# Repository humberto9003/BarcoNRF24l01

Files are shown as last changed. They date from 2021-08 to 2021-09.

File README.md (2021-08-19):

# Enlace con NRF24L01
Este repositorio contiene el programa para comunicar dos modulos NRF24L01, enviando las señales analogicas de un joystick por radiocomunicacion (2.4GHZ) para controlar un servomotor SG90 y un motor Brushless.

### Requisitos
Para que el código de este repositorio funcione, es necesario contar con lo siguiente:

- Arduino Uno
- IDE de Arduino 1.8 o superior
- Biblioteca RF24
- Servomotor SG90
- Motor Brushless A2212 Kv1400 / Kv2200
- NRF24L01
- Regulador de Voltaje para el NR24L01
- Modulo Joystick de dos ejes.

### Guías

Puedes obtener la biblioteca RF24 desde el siguiente enlace.

https://github.com/nRF24/RF24

Para conocer mas acerca del modulo NRF24L01 puede consultarlo en el siguiente enlace.

http://robots-argentina.com.ar/didactica/arduino-comunicacion-inalambrica-con-nrf24l01/

### Funcionamiento

Para observar el funcionamiento de este proyecto deberás realizar lo siguiente.

1. Configuarar los pines para el motor,servomotor y joystick de tu preferencia en el codigo de RX y Tx.
2. Si no cunetas con un NodeMCU se puede sustituir con otro arduino, solo tendrias que configuarar los pines de igual manera que el codigo de TX.
3. Alimentar el modulo NRF24L01 unicamete y exclusivamente con el regulador de  3.3V
4. En caso de usar el motor alimentarlo de una bateria externa y no del arduino ya que este no proporciona la corriente suficiente.

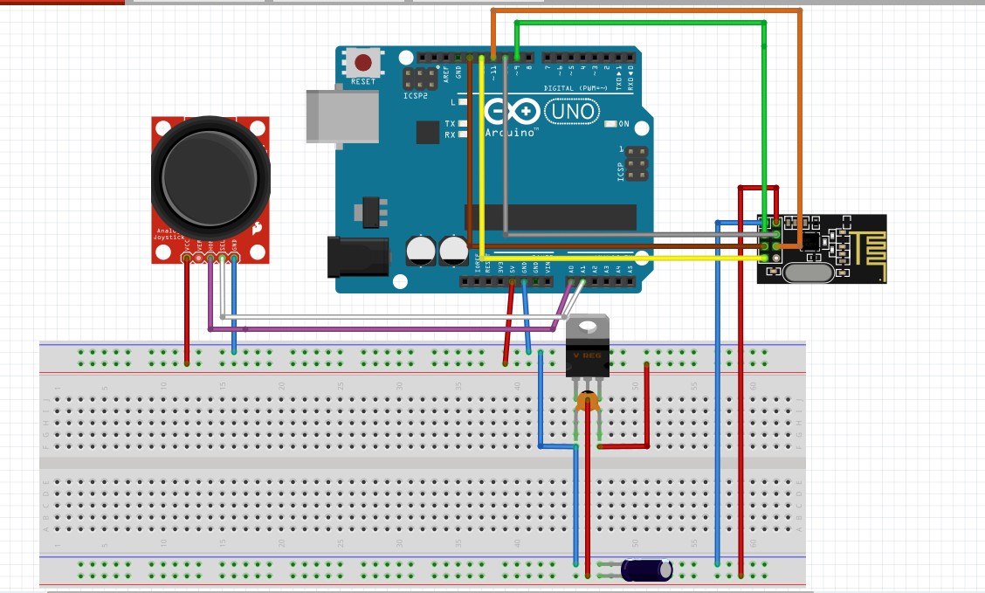
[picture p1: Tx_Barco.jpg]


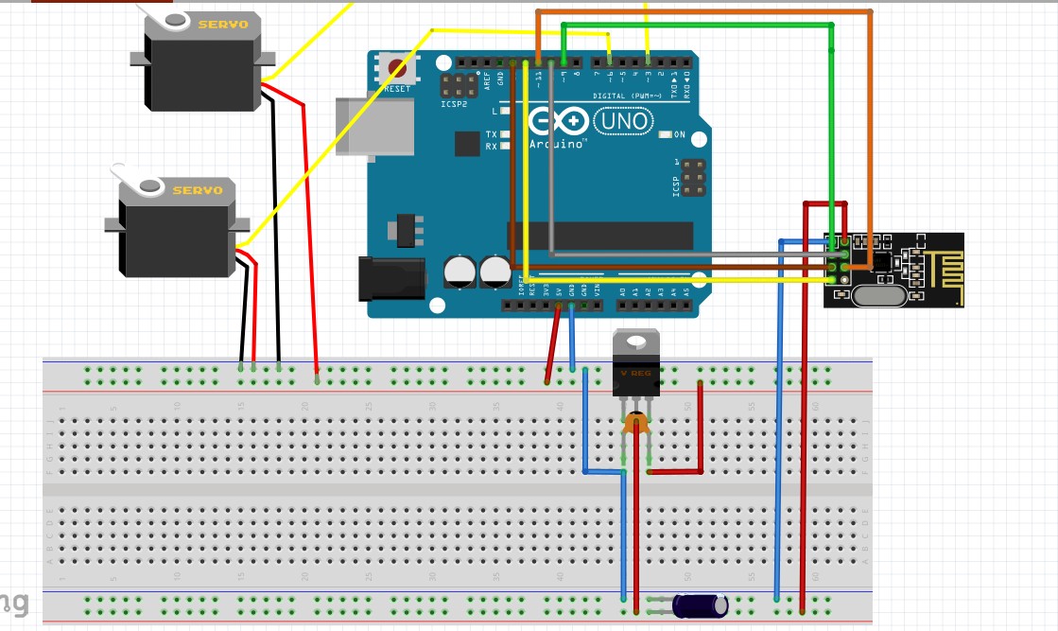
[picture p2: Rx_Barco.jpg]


Podras comunicar dos arduinos por radiocomunicación, para este caso en particular poder manipular un servomor y motor con un Joystick. 

Por: [Humberto Pastor](https://https://github.com/humberto9003)

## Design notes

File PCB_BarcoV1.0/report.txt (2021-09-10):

Información: Checking netlist symbol footprint "J1:/60B9BEF3:TerminalBlock_Phoenix:TerminalBlock_Phoenix_PT-1,5-2-5.0-H_1x02_P5.00mm_Horizontal".
Información: Checking netlist symbol footprint "Y1:/60B92542:Crystal:Crystal_HC49-4H_Vertical".
Información: Checking netlist symbol footprint "U3:/60B7981D:Package_DIP:DIP-28_W7.62mm".
Información: Checking netlist symbol footprint "U2:/60B07A03:Package_TO_SOT_SMD:SOT-223-3_TabPin2".
Información: Checking netlist symbol footprint "U1:/60B08B95:Package_TO_SOT_SMD:SOT-223-3_TabPin2".
Información: Checking netlist symbol footprint "SW1:/60C895E8:Button_Switch_THT:SW_PUSH_6mm_H5mm".
Información: Checking netlist symbol footprint "R1:/60C85715:Resistor_THT:R_Axial_DIN0411_L9.9mm_D3.6mm_P12.70mm_Horizontal".
Información: Checking netlist symbol footprint "J4:/60CA2C0F:Connector_PinSocket_2.00mm:PinSocket_2x04_P2.00mm_Vertical".
Información: Checking netlist symbol footprint "J3:/60CF4BA0:Connector_PinSocket_2.00mm:PinSocket_1x03_P2.00mm_Vertical".
Información: Checking netlist symbol footprint "J2:/60D07454:Connector_PinSocket_2.00mm:PinSocket_1x03_P2.00mm_Vertical".
Información: Checking netlist symbol footprint "D1:/60C0918B:Diode_THT:D_DO-41_SOD81_P10.16mm_Horizontal".
Información: Checking netlist symbol footprint "C7:/60B9B430:Capacitor_THT:C_Disc_D5.0mm_W2.5mm_P2.50mm".
Información: Checking netlist symbol footprint "C6:/60B980F9:Capacitor_THT:C_Disc_D5.0mm_W2.5mm_P2.50mm".
Información: Checking netlist symbol footprint "C5:/60CAEE1E:Capacitor_THT:C_Radial_D5.0mm_H5.0mm_P2.00mm".
Información: Checking netlist symbol footprint "C4:/60C403EC:Capacitor_THT:CP_Radial_D5.0mm_P2.00mm".
Información: Checking netlist symbol footprint "C3:/60B0BA73:Capacitor_THT:CP_Radial_Tantal_D10.5mm_P5.00mm".
Información: Checking netlist symbol footprint "C2:/60B8D440:Capacitor_THT:CP_Radial_Tantal_D10.5mm_P5.00mm".
Información: Checking netlist symbol footprint "C1:/60B0AC10:Capacitor_SMD:CP_Elec_5x5.4".
Aviso: Footprint of C5 changed: board footprint "Capacitor_THT:C_Disc_D11.0mm_W5.0mm_P5.00mm", netlist footprint "Capacitor_THT:C_Radial_D5.0mm_H5.0mm_P2.00mm".

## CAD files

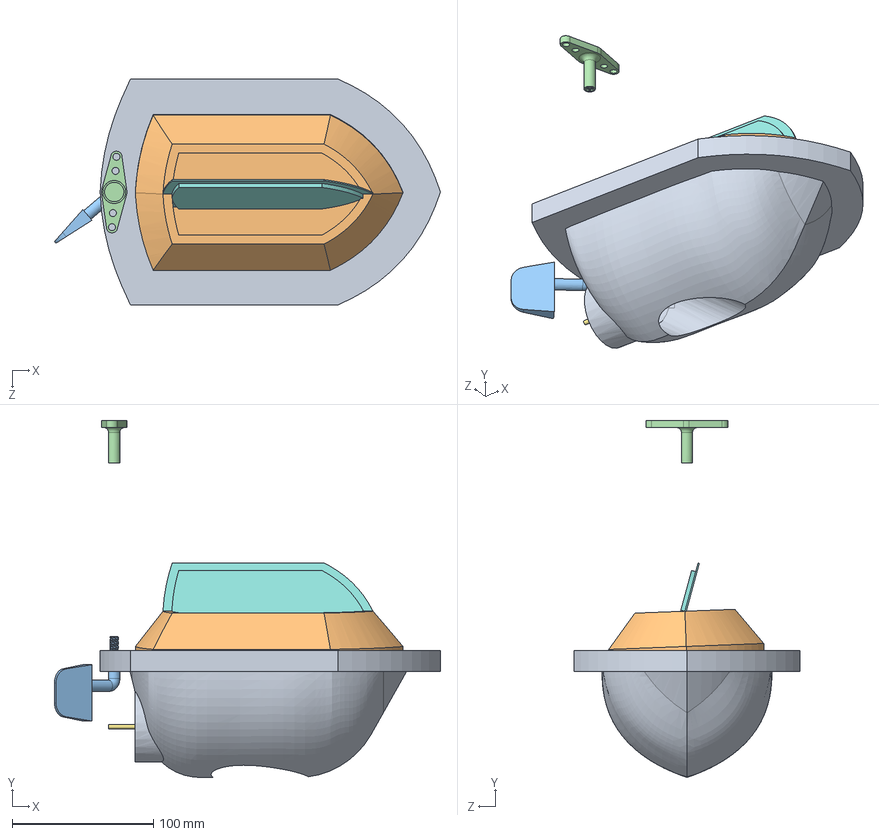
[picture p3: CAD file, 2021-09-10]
Barco/Ensamblaje1.SLDASM
273.6 x 253.1 x 160.0 mm
Barco
tapaB
propela
propela2
motor
Helice
Varilla
TapaC

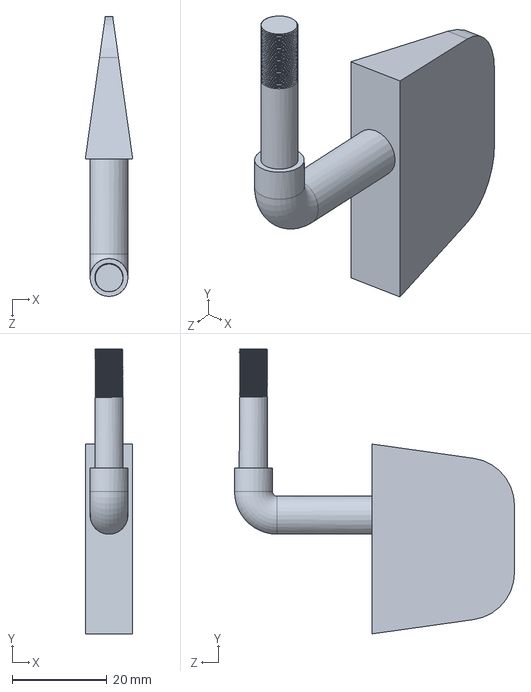
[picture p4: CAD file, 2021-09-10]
Barco/propela.SLDPRT
10.0 x 60.0 x 59.0 mm

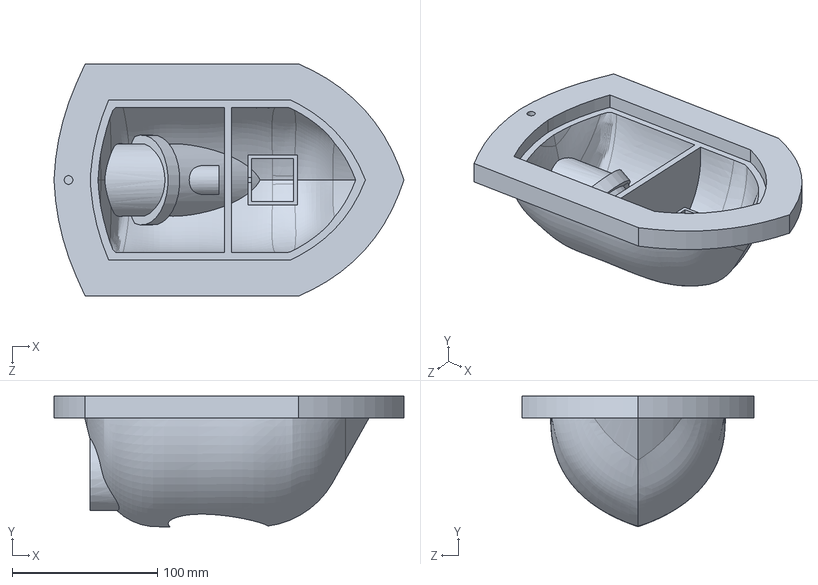
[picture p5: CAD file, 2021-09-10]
Barco/Barco.SLDPRT
241.3 x 90.0 x 160.0 mm

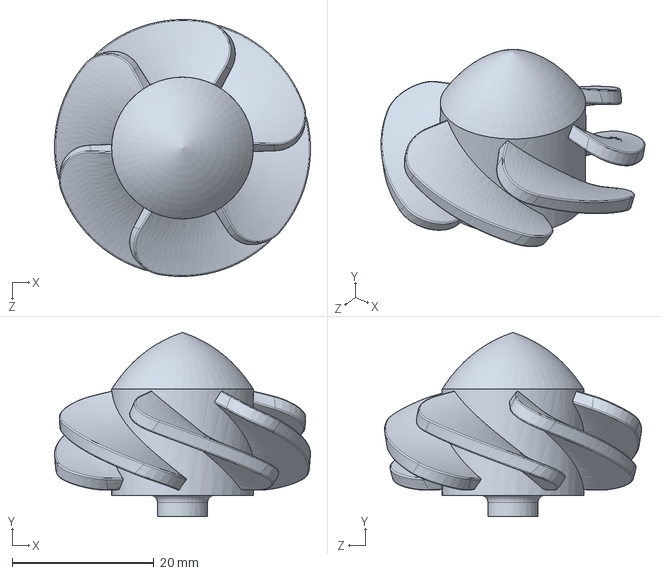
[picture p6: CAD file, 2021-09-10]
Barco/Helice.SLDPRT
36.1 x 26.0 x 36.3 mm

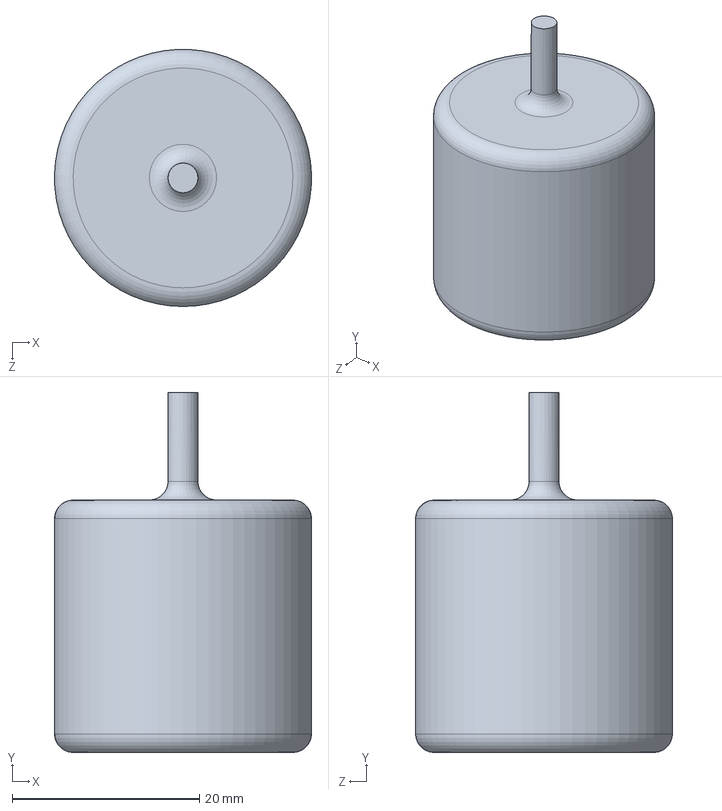
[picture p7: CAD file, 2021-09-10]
Barco/motor.SLDPRT
27.5 x 38.5 x 27.5 mm

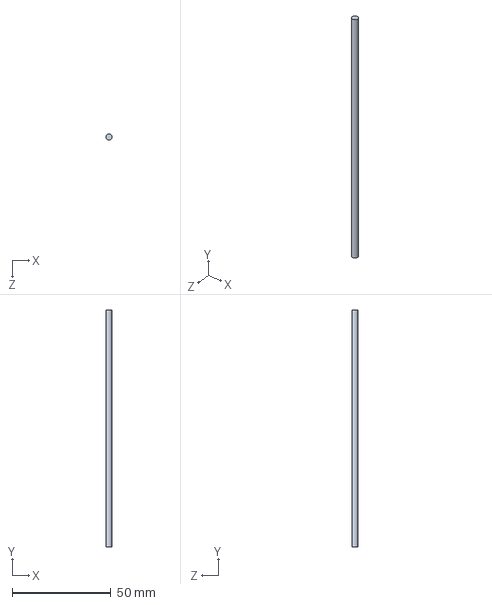
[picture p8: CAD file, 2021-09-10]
Barco/Varilla.SLDPRT
3.20 x 120.0 x 3.20 mm

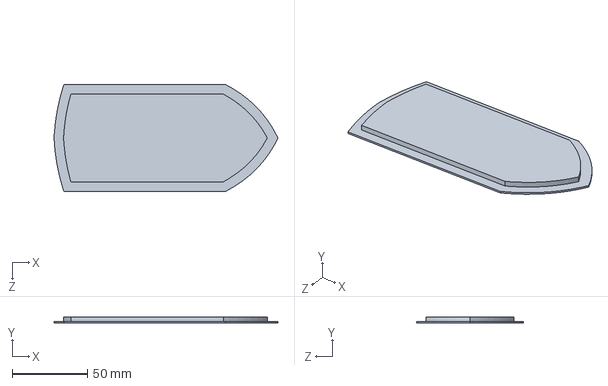
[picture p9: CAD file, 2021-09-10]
Barco/TapaC.SLDPRT
148.9 x 4.00 x 70.9 mm

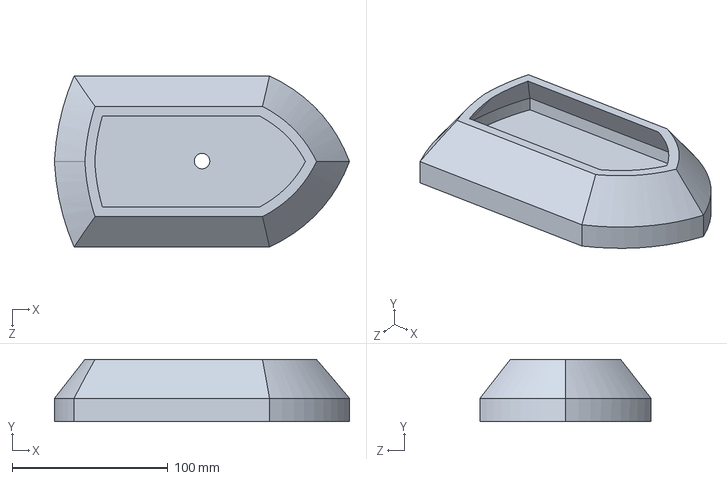
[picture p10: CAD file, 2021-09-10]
Barco/tapaB.SLDPRT
189.7 x 40.0 x 110.0 mm

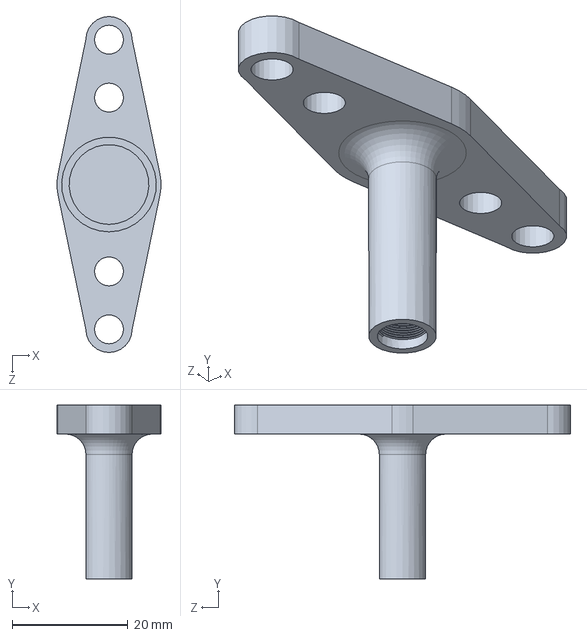
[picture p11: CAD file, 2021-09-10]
Barco/propela2.SLDPRT
17.9 x 30.0 x 58.0 mm

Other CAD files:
Barco/Barco.STL
Barco/makeProjectedPlanarWire.x_t
Barco/propela.STL
Barco/propela2.STL
Barco/tapaB.STL

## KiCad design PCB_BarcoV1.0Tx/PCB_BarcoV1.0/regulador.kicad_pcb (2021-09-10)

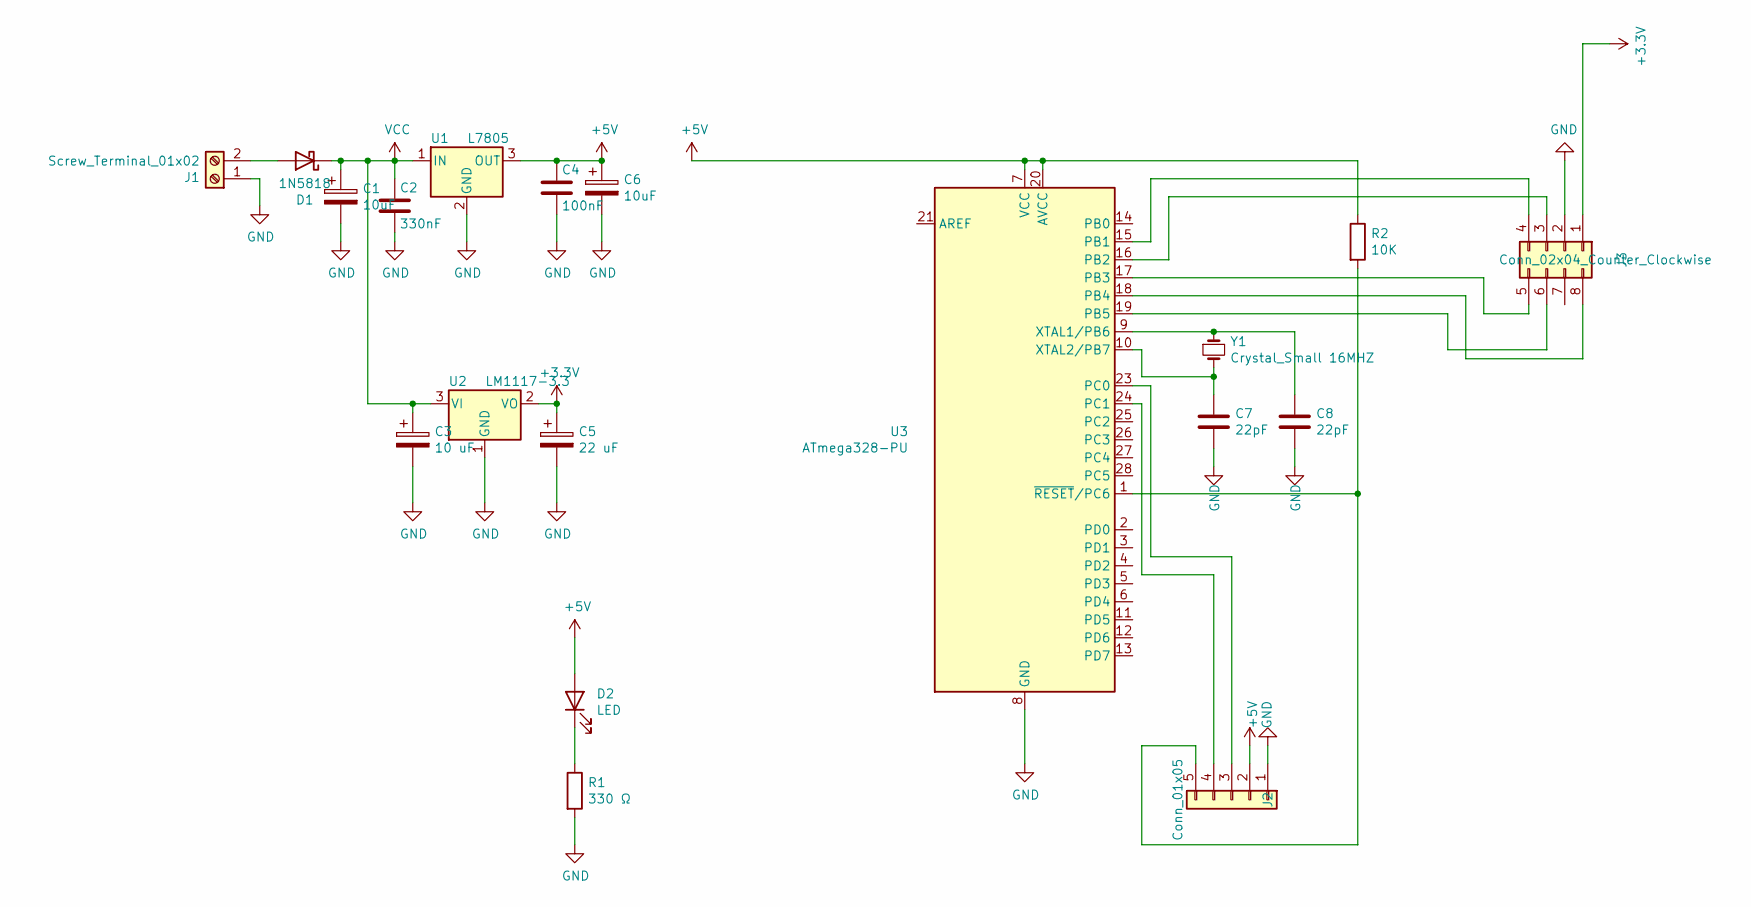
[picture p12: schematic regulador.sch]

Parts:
C1, C6: 10uF; CP_Radial_D5.0mm_P2.50mm
C2: 330nF; C_Disc_D6.0mm_W2.5mm_P5.00mm
C3: 10 uF; CP_Radial_D5.0mm_P2.50mm
C4: 100nF; C_Disc_D6.0mm_W2.5mm_P5.00mm
C5: 22 uF; CP_Radial_Tantal_D6.0mm_P2.50mm
C7, C8: 22pF; C_Disc_D5.0mm_W2.5mm_P2.50mm
D1: 1N5818; D_DO-41_SOD81_P10.16mm_Horizontal
D2: LED; LED_D5.0mm
J1: Screw_Terminal_01x02; TerminalBlock_Phoenix_PT-1,5-2-5.0-H_1x02_P5.00mm_Horizontal
J2: Conn_01x05; PinHeader_1x05_P2.54mm_Vertical
J3: Conn_02x04_Counter_Clockwise; PinSocket_2x04_P2.54mm_Vertical
R1: 330 Ω; R_Axial_DIN0207_L6.3mm_D2.5mm_P10.16mm_Horizontal
R2: 10K; R_Axial_DIN0207_L6.3mm_D2.5mm_P10.16mm_Horizontal
U1: L7805; TO-220-3_Horizontal_TabDown
U2: LM1117-3.3; TO-220-3_Horizontal_TabDown
U3: ATmega328-PU; DIP-28_W7.62mm_Socket_LongPads
Y1: Crystal_Small 16MHZ; Crystal_HC49-4H_Vertical

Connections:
+3V3: C5.1, J3.1, U2.2 (VO)
+5V: C4.1, C6.1, D2.2 (A), J2.2, R2.1, U1.3 (OUT), U3.7 (VCC), U3.20 (AVCC)
GND: C1.2, C2.2, C3.2, C4.2, C5.2, C6.2, C7.2, C8.2, J1.1, J2.1, J3.2, R1.2, U1.2 (GND), U2.1 (GND), U3.8 (GND), U3.22 (GND)
unnamed: C7.1, U3.10 (XTAL2/PB7), Y1.2
unnamed: C8.1, U3.9 (XTAL1/PB6), Y1.1
unnamed: D1.2 (A), J1.2
unnamed: D2.1 (K), R1.1
unnamed: J2.3, U3.23 (PC0)
unnamed: J2.4, U3.24 (PC1)
unnamed: J2.5, R2.2, U3.1 (~RESET~/PC6)
unnamed: J3.3, U3.16 (PB2)
unnamed: J3.4, U3.15 (PB1)
unnamed: J3.5, U3.17 (PB3)
unnamed: J3.6, U3.19 (PB5)
unnamed: J3.8, U3.18 (PB4)
VCC: C1.1, C2.1, C3.1, D1.1 (K), U1.1 (IN), U2.3 (VI)

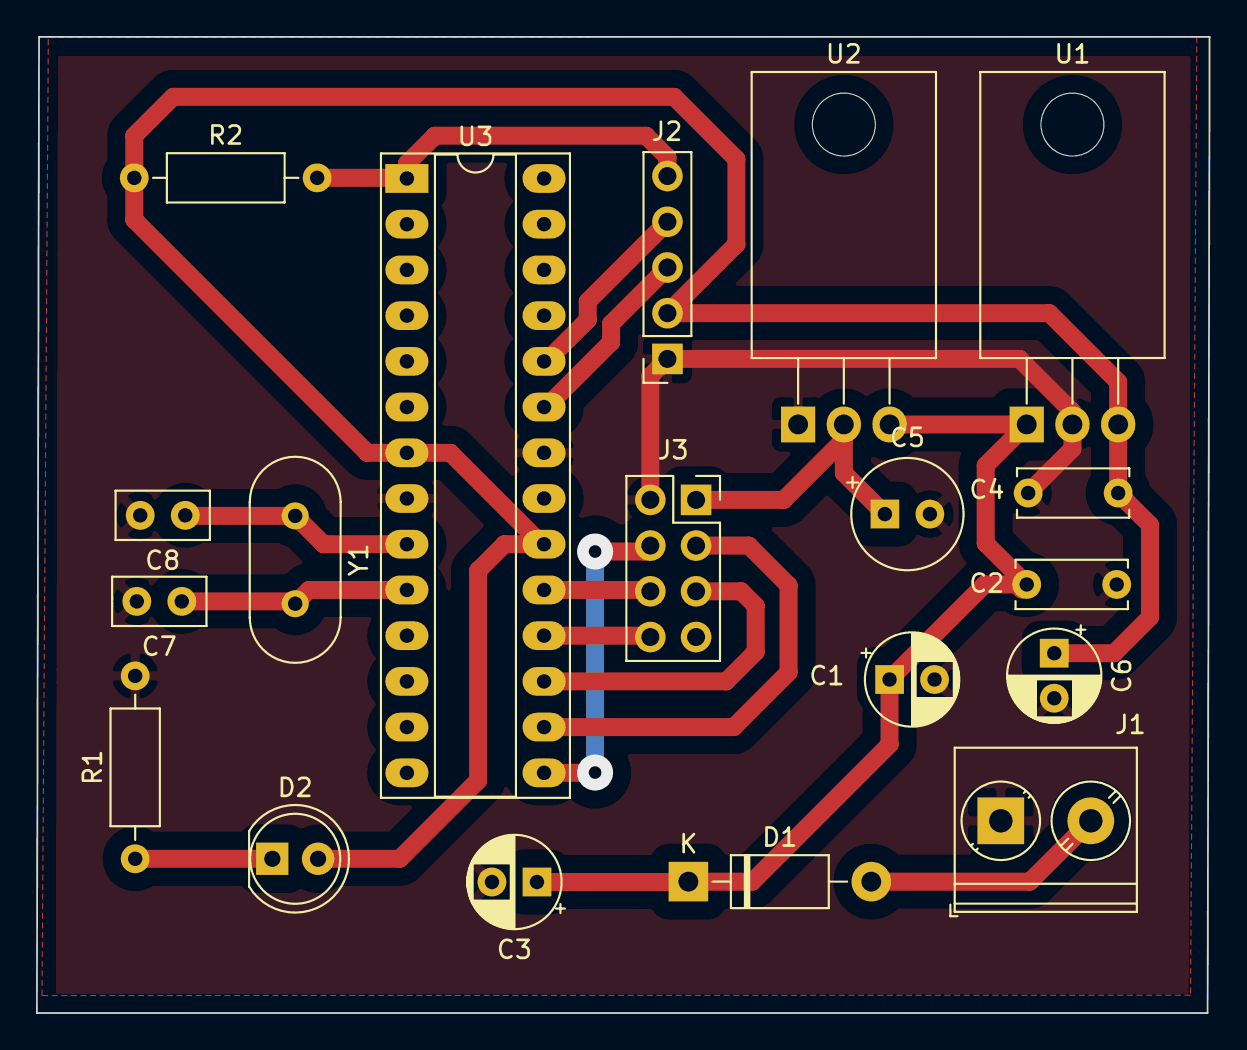
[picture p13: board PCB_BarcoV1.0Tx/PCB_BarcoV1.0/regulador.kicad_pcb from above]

Board: 2 copper layers, 65.2 x 54.2 mm, 19 parts (0 on the bottom side), 16 nets.

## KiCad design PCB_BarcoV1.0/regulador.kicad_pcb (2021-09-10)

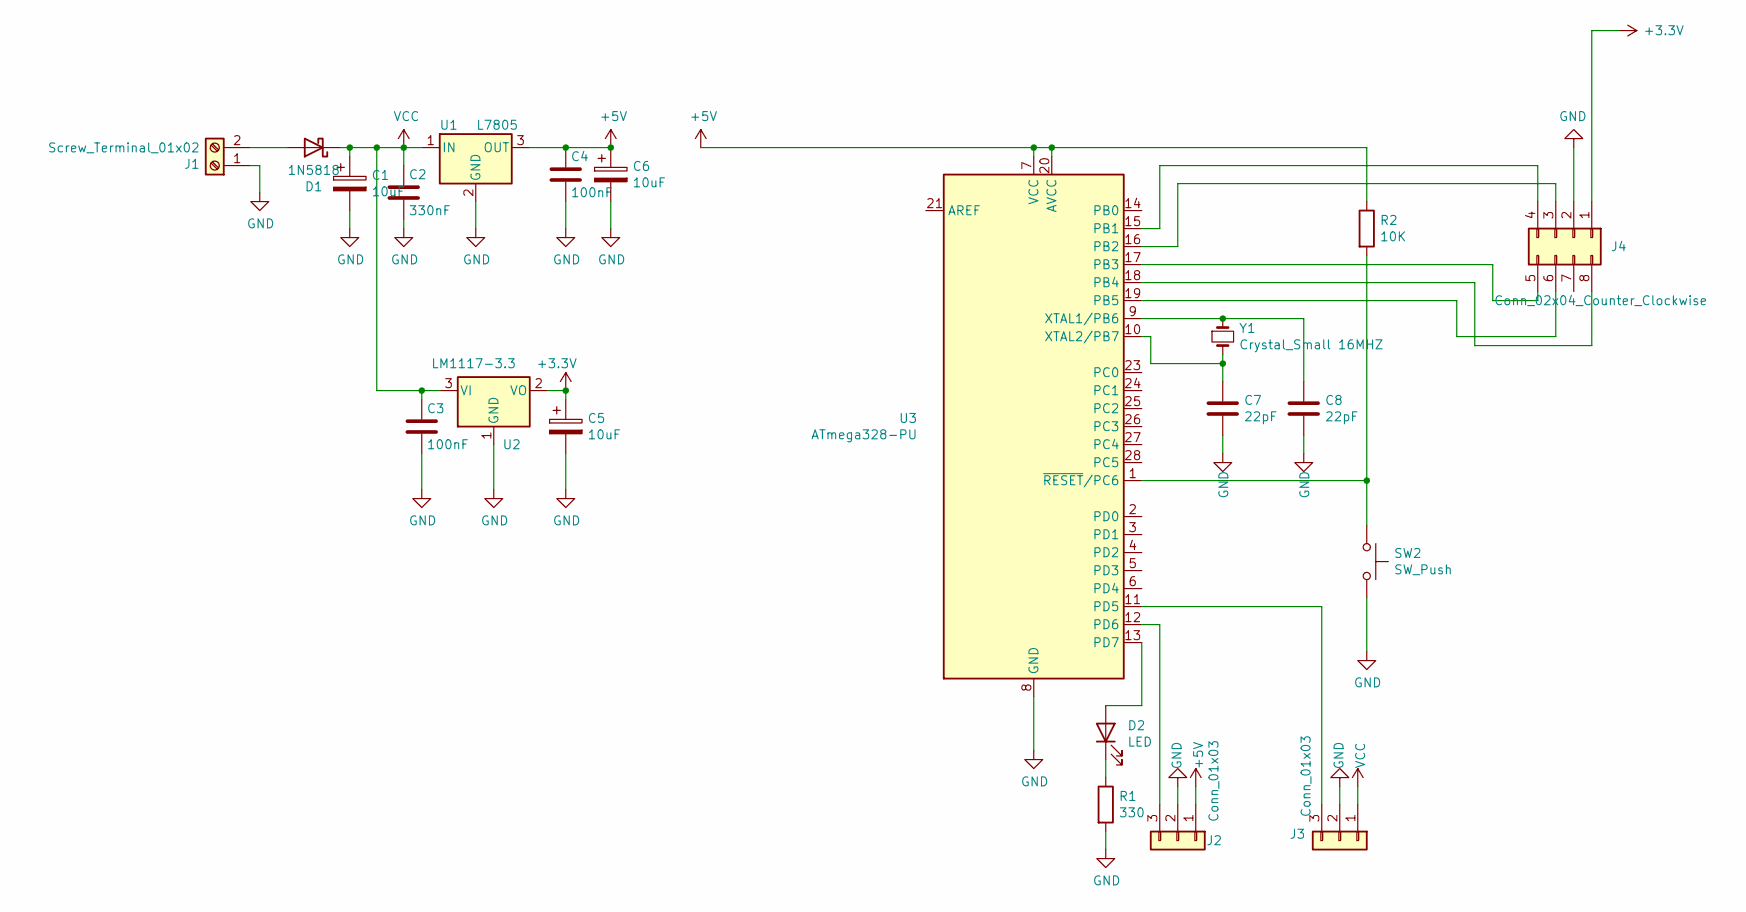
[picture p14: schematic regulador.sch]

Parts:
C1, C5, C6: 10uF; CP_Radial_D5.0mm_P2.50mm
C2: 330nF; C_Disc_D6.0mm_W2.5mm_P5.00mm
C3, C4: 100nF; C_Disc_D6.0mm_W2.5mm_P5.00mm
C7, C8: 22pF; C_Disc_D5.0mm_W2.5mm_P2.50mm
D1: 1N5818; D_DO-41_SOD81_P10.16mm_Horizontal
D2: LED; LED_D5.0mm
J1: Screw_Terminal_01x02; TerminalBlock_Phoenix_PT-1,5-2-5.0-H_1x02_P5.00mm_Horizontal
J2: Conn_01x03; PinHeader_1x03_P2.54mm_Vertical
J3: Conn_01x03; PinSocket_1x03_P2.54mm_Vertical
J4: Conn_02x04_Counter_Clockwise; PinSocket_2x04_P2.54mm_Vertical
R1: 330; R_Axial_DIN0207_L6.3mm_D2.5mm_P10.16mm_Horizontal
R2: 10K; R_Axial_DIN0207_L6.3mm_D2.5mm_P10.16mm_Horizontal
SW2: SW_Push; SW_PUSH_6mm_H5mm
U1: L7805; TO-220-3_Horizontal_TabDown
U2: LM1117-3.3; TO-220-3_Horizontal_TabDown
U3: ATmega328-PU; DIP-28_W7.62mm_Socket_LongPads
Y1: Crystal_Small 16MHZ; Crystal_HC49-4H_Vertical

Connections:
+3V3: C5.1, J4.1, U2.2 (VO)
+5V: C4.1, C6.1, J2.1, R2.1, U1.3 (OUT), U3.7 (VCC), U3.20 (AVCC)
GND: C1.2, C2.2, C3.2, C4.2, C5.2, C6.2, C7.2, C8.2, J1.1, J2.2, J3.2, J4.2, R1.2, SW2.2, U1.2 (GND), U2.1 (GND), U3.8 (GND), U3.22 (GND)
unnamed: C7.1, U3.10 (XTAL2/PB7), Y1.2
unnamed: C8.1, U3.9 (XTAL1/PB6), Y1.1
unnamed: D1.2 (A), J1.2
unnamed: D2.1 (K), R1.1
unnamed: D2.2 (A), U3.13 (PD7)
unnamed: J2.3, U3.12 (PD6)
unnamed: J3.3, U3.11 (PD5)
unnamed: J4.3, U3.16 (PB2)
unnamed: J4.4, U3.15 (PB1)
unnamed: J4.5, U3.17 (PB3)
unnamed: J4.6, U3.19 (PB5)
unnamed: J4.8, U3.18 (PB4)
unnamed: R2.2, SW2.1, U3.1 (~RESET~/PC6)
VCC: C1.1, C2.1, C3.1, D1.1 (K), J3.1, U1.1 (IN), U2.3 (VI)

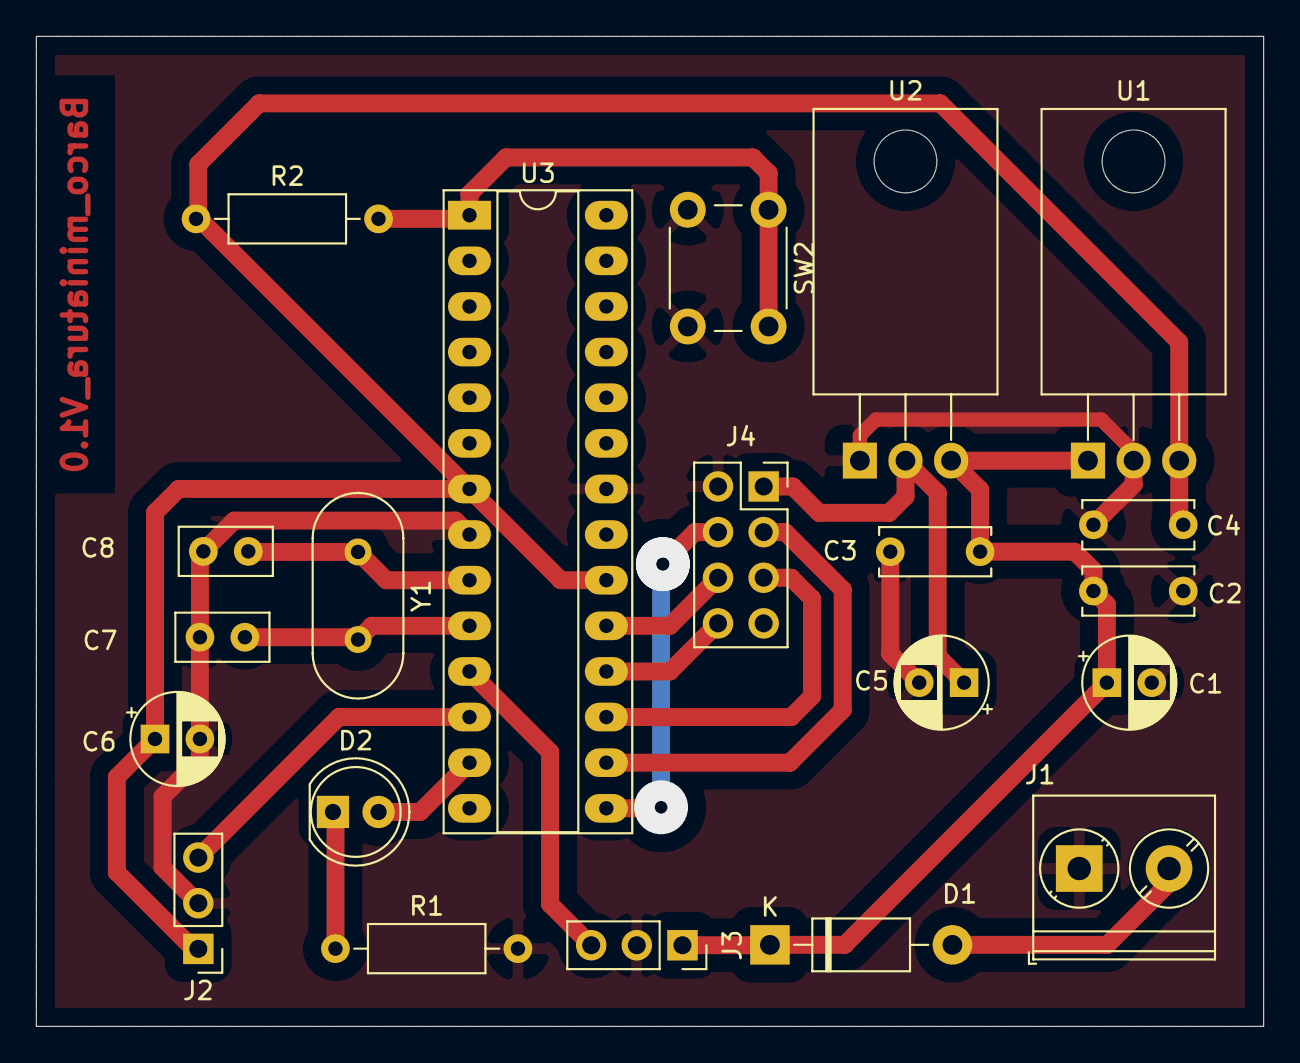
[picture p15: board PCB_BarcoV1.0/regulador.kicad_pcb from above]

Board: 2 copper layers, 68.3 x 55.1 mm, 21 parts (0 on the bottom side), 17 nets.

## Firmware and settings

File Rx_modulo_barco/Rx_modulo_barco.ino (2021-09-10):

#include <SPI.h>
#include <nRF24L01.h>
#include <RF24.h>
#include <Servo.h>          // Incluir la librería Servo
Servo servo1;   

#define LED 7
#define motor 5

/*volatile unsigned int cuenta = 0;
bool ESTADO = false;*/


unsigned long timeNow, timeLast; // Variables de control de tiempo no bloqueante
int wait = 500;

 
/*const int pinCE = D4;
const int pinCSN = D8;
// SCLK pin D5, MISO pin D6, MOSI pin D7, CS pin D8.
RF24 radio(pinCE, pinCSN);
// Single radio pipe address for the 2 nodes to communicate.
const uint64_t pipe = 0xE8E8F0F0E1LL;*/

const int pinCE = 9;
const int pinCSN = 10;

// SCK pin 13, MISO pin 12, MOSI pin 11,SS pin 10 
RF24 radio(pinCE, pinCSN);
// Single radio pipe address for the 2 nodes to communicate.
const uint64_t pipe = 0xE8E8F0F0E1LL;
short data[2];



void setup()
{
   radio.begin();
   /*Serial.begin(9600); */
   radio.setPALevel(RF24_PA_MAX);
   radio.setDataRate(RF24_2MBPS);
   radio.setChannel(100);
   radio.openReadingPipe(1, pipe);
   radio.startListening();
   servo1.attach(6) ;  // Conectar servo1 al pin 5
   
  /*SREG = (SREG & 0b01111111); //Desabilitar interrupciones
   TIMSK2 = TIMSK2|0b00000001; //Habilita la interrupcion por desbordamiento
   TCCR2B = 0b00000111; //Configura preescala para que FT2 sea de 7812.5Hz
   SREG = (SREG & 0b01111111) | 0b10000000; //Habilitar interrupciones //Desabilitar interrupciones
*/
   pinMode(LED, OUTPUT);
   timeLast = millis (); // Inicia el control de tiempo*/
}
 
void loop()
{
  
  
   if (radio.available())
   {    
      radio.read(&data, sizeof data);
        //mostrar valores por serial
      int angulo  = map( data[0], 0, 1024, 0, 180);
      int motorPWM = map( data[1], 0, 1024, 0,255);
      servo1.write(angulo);
      analogWrite(motor, motorPWM);
      /*Serial.print("X:" );
      Serial.print(angulo);
      Serial.print(" | Y: ");
      Serial.println(motorPWM);

      /*digitalWrite(LED, HIGH);   // turn the LED on (HIGH is the voltage level)*/
      
      timeNow = millis(); // Control de tiempo para esperas no bloqueantes
      if (timeNow - timeLast > wait) { // Manda un mensaje por MQTT cada cinco segundos
           timeLast = timeNow; // Actualización de seguimiento de tiempo
           digitalWrite(LED, HIGH); 
      }
      else {
           digitalWrite(LED, LOW);   
      }  
    }
    else{
      /*Serial.println("No radio available");*/
      digitalWrite(LED, LOW);   // turn the LED on (HIGH is the voltage level)*/
    }
      
}

/**ISR(TIMER2_OVF_vect){
    cuenta++;
  if (radio.available()) {
    if(cuenta > 7) {
      digitalWrite(LED,ESTADO);
      ESTADO = !ESTADO;
      cuenta=0;
    }
  }
  else{
      digitalWrite(LED, LOW);   // turn the LED on (HIGH is the voltage level)*/
  /*}
}*/

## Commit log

2021-08-19 files of prototype of a radio frecuency ship
2021-08-19 delete image
    Corrigiendo nombre de imagen
2021-09-10 files add
    [Barco.SLDPRT, Barco.STL, Ensamblaje1.SLDASM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]
